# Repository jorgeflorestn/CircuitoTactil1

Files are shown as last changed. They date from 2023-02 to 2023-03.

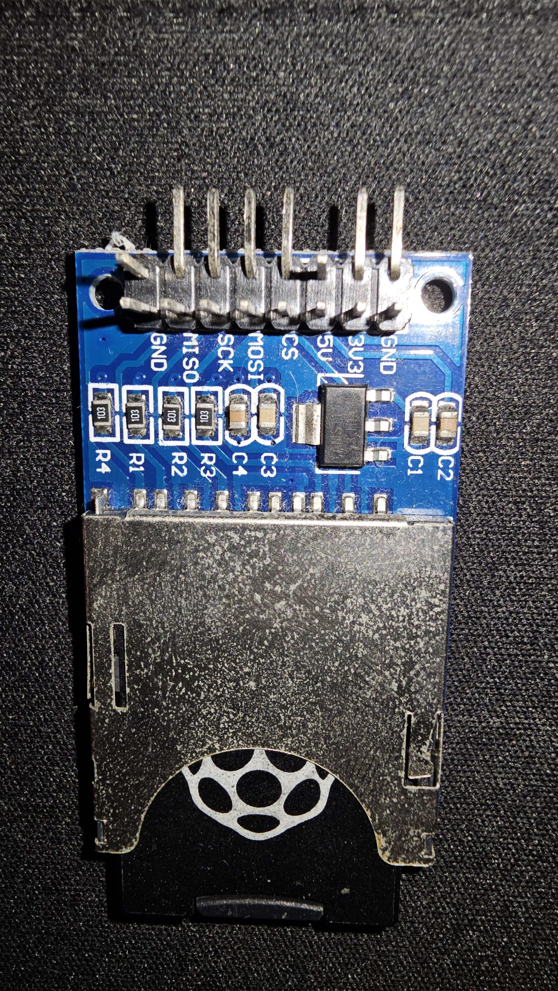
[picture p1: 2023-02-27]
Pictures/Diagrams/20230223_190610.jpg

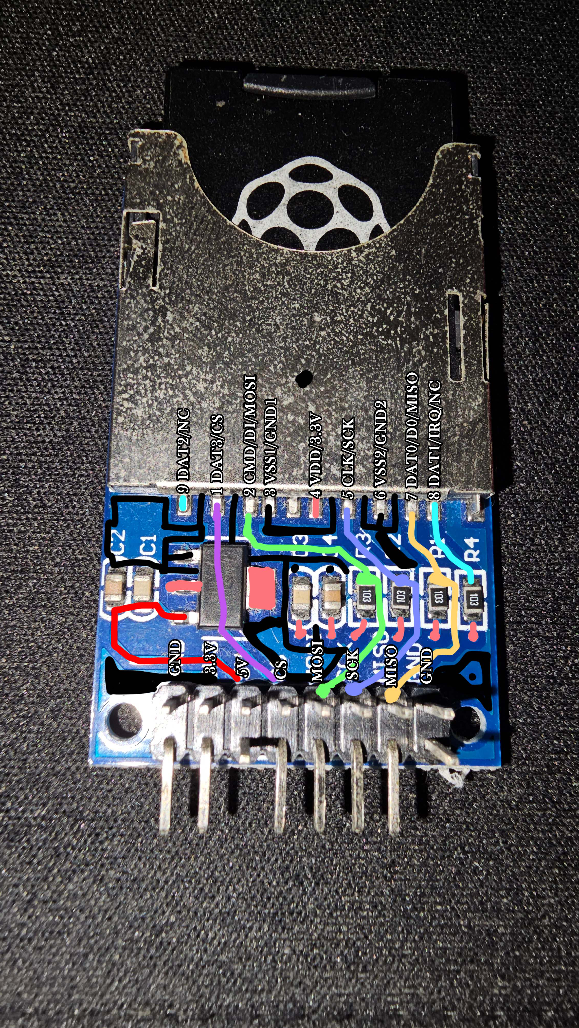
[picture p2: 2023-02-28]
Pictures/Diagrams/20230223_190610S.jpg

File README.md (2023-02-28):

# Circuito Tactil NTC UADY-CICY
Circuito para la detección de contacto en sensores nanoestructurados.

## Por hacer y revisar (de prioritario a no urgente)
- **Checar valores de _resistencias y capacitores_.**
<sub>(los del regulador deben ser 10uF en ambas salidas para evitar ruido, poner en paralelo uno de 100nf ceramico para reducir la Rint de ambos)</sub>
- Hacer tabla con características de mcu/mux/potdig/opamp para presentar a Francis y compararlo con equipo Keysight 34980A y 32923A
- ~~Añadir capacitores al lado de la entrada de 3.3v MCU ✓~~
- ~~Controlar la salida 2 del regulador para encender/apagar circuitos ✓~~ (checar consumo? aguanta el ic?)
- ~~Conectar MCU a pines ✓~~
- ~~Revisar mosfet Q1, se están usando como canal P y no N ✓~~
- ~~Validar secuencia en MUXes ✓~~(Checar que cable plano tenga los mismos pines en ambos extremos 1:1)
- ~~Editar footprint de nina para quitar todos los gpio no usados ✓~~
- ~~Validar conexión spi y componentes para micro SD ✓~~
- ~~Etiquetas en pines. ✓~~
- ~~tapar vias no importantes (reduciendo su tamaño <13 mils) ✓~~

## Extras a añadir
- ~~Añadir headers para sacar I2C y SPI ✓~~
- ~~Añadir testpoints en muxes ✓~~
- ~~Jumper para saltar de 3.3v a 5v ✓~~

### Si nos da tiempo 
- Añadir ic para carga y descarga de baterías (queda un espacio grande donde podemos añadir el cargador de pilas)
**(Si se añade, se debe aislar los 5v del usb y los 4.2 de la pila)**.
- Integrar ADC ADS1220 (FUTURO (puerto i2c disponible))
- ~~Añadir conector plano de +42 pines (básicamente se añadió en el punto de los testpoints en muxes)~~

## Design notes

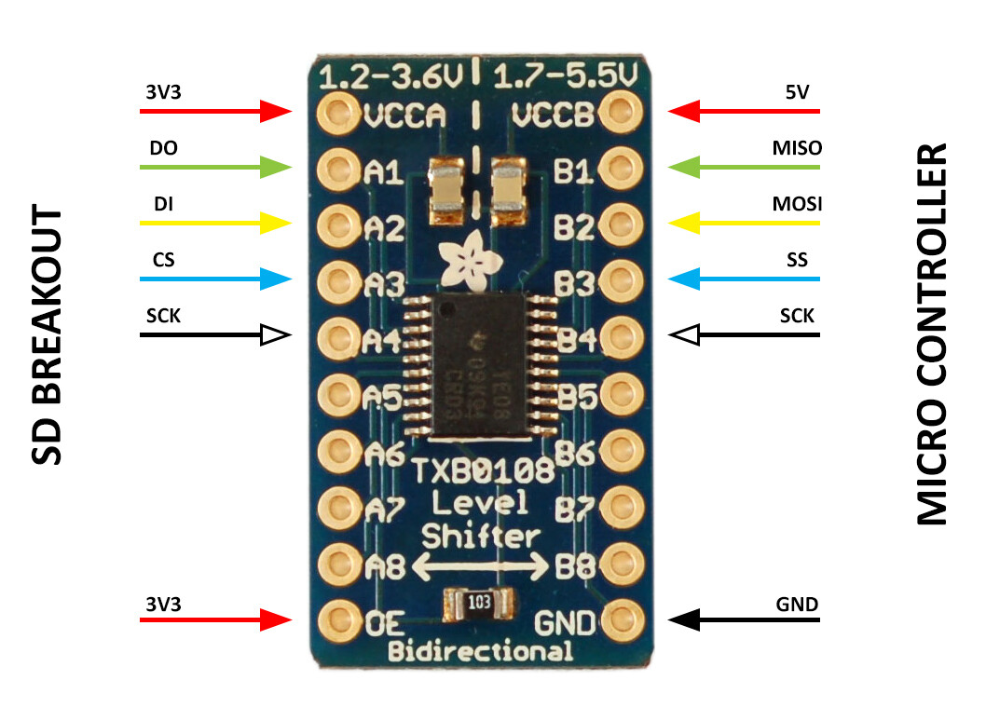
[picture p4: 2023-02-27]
Pictures/Diagrams/txb0108_LRG-amk.jpg

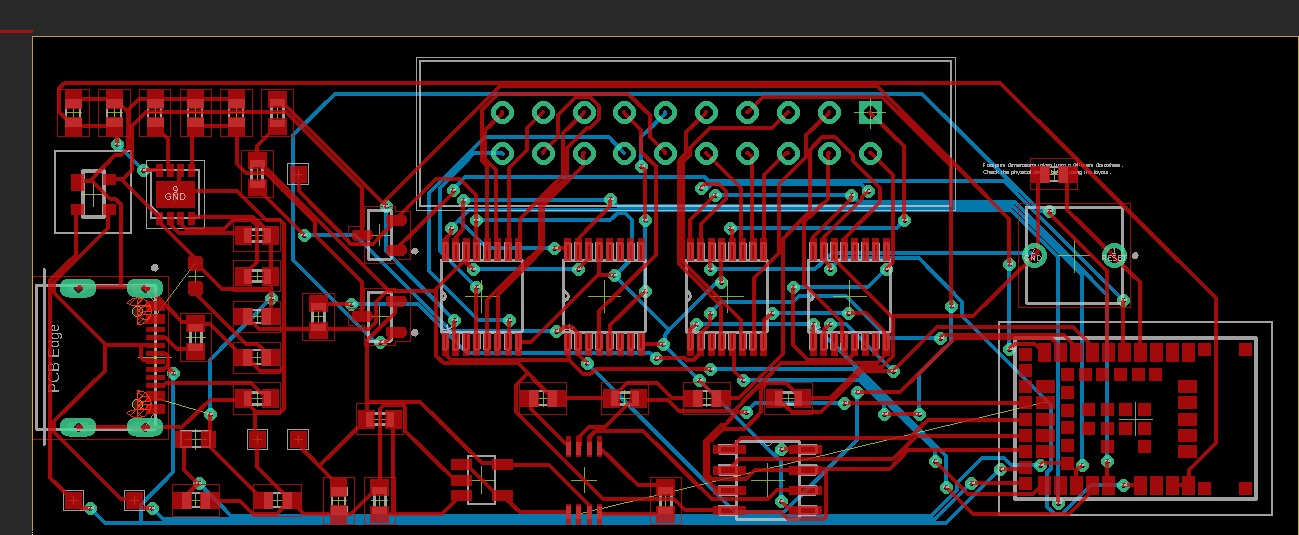
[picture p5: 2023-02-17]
Pictures/Diagrams/WhatsApp Image 2023-02-15 at 4.39.45 PM.jpeg

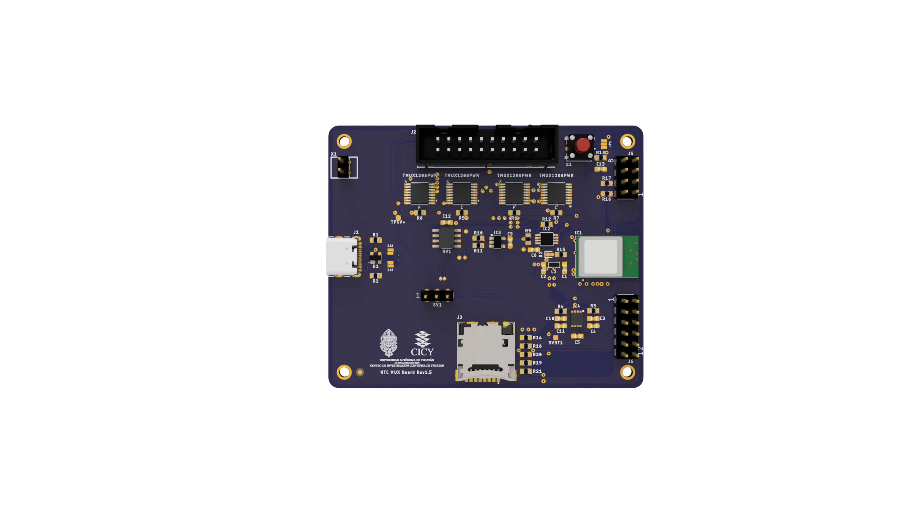
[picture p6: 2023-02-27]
Pictures/7006e35c-3277-4497-81c9-2658856942b5.PNG

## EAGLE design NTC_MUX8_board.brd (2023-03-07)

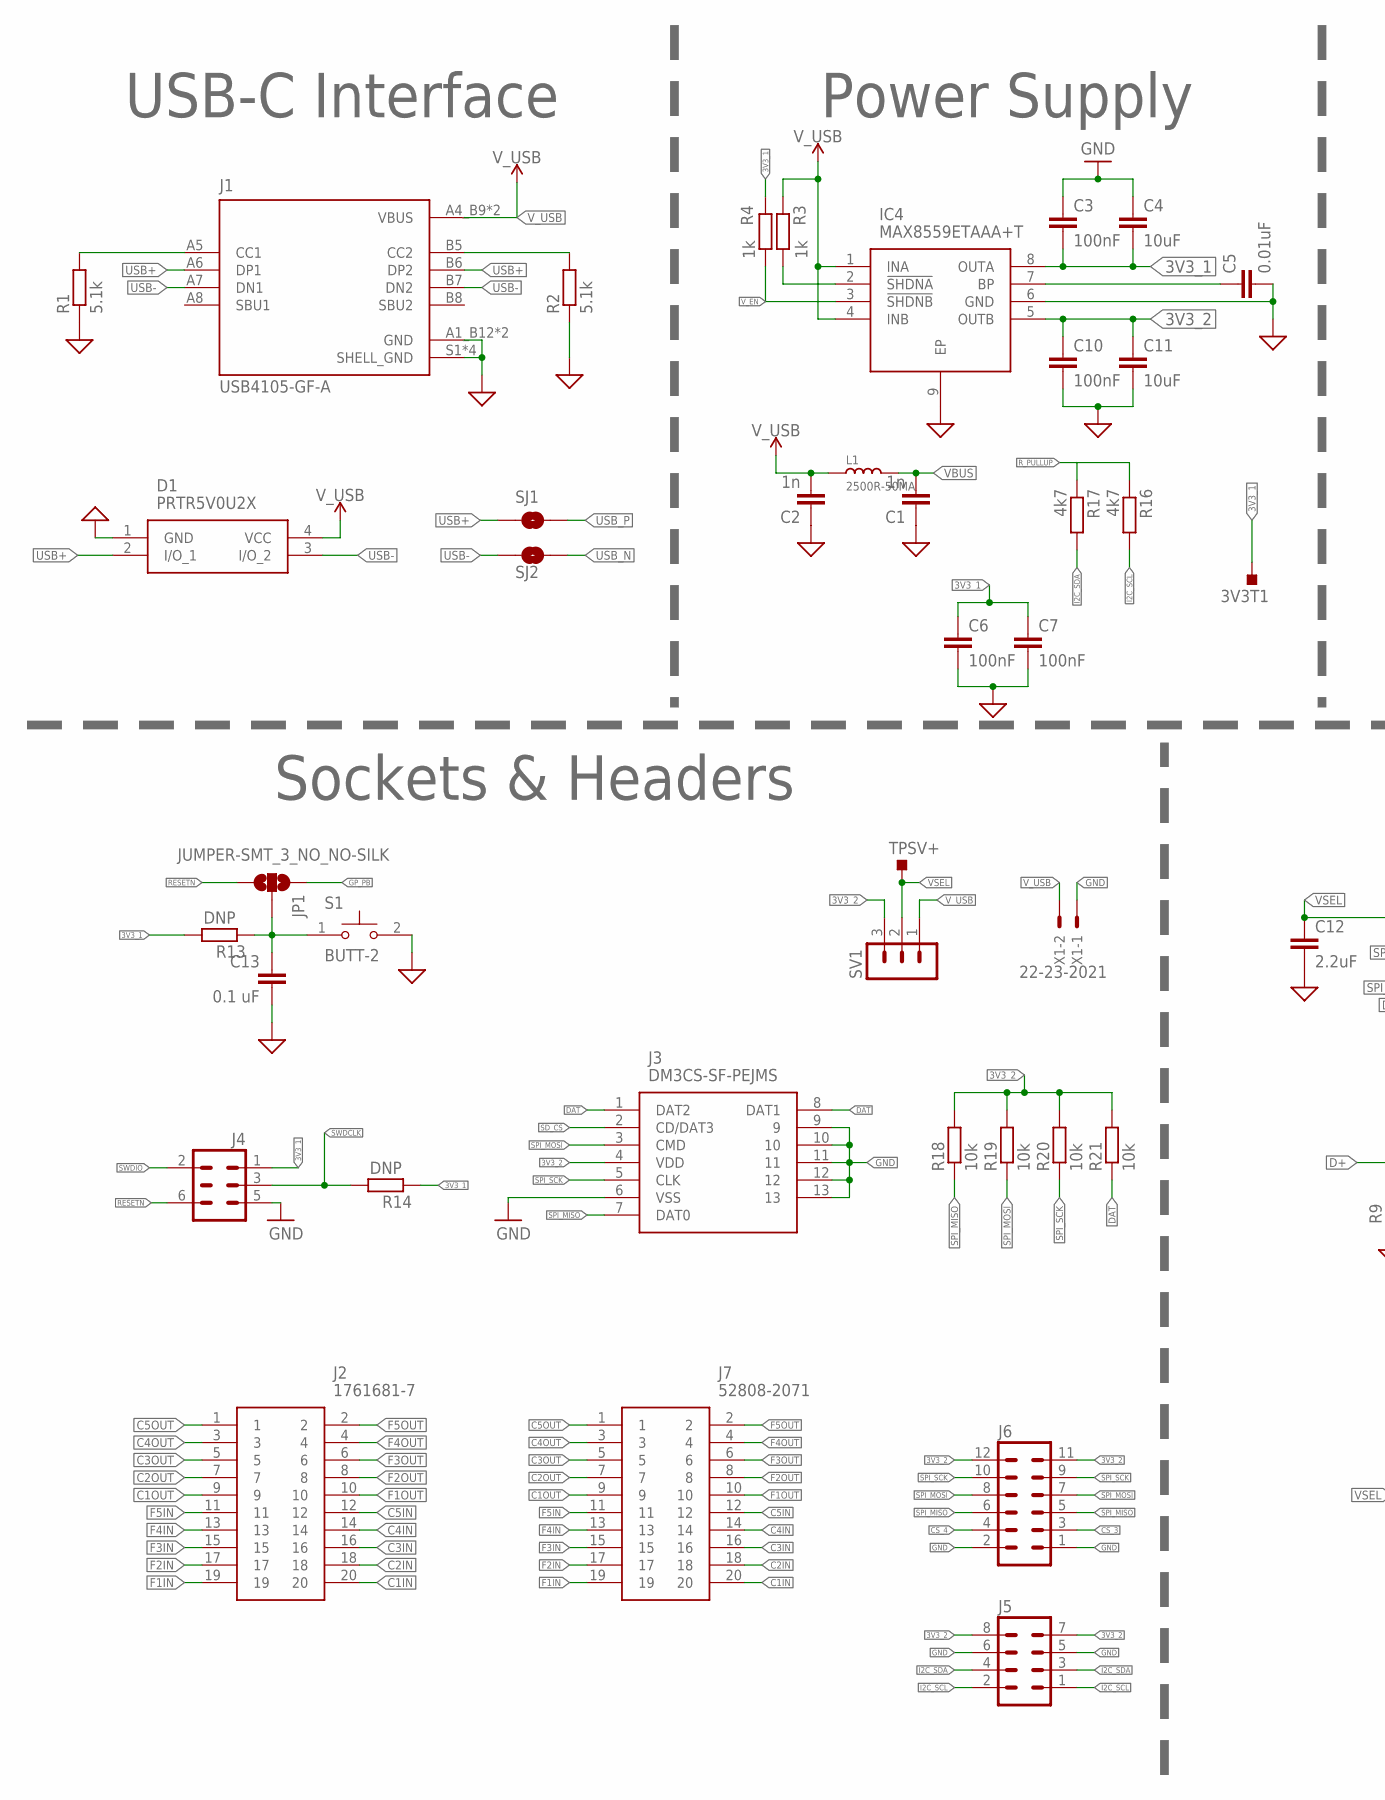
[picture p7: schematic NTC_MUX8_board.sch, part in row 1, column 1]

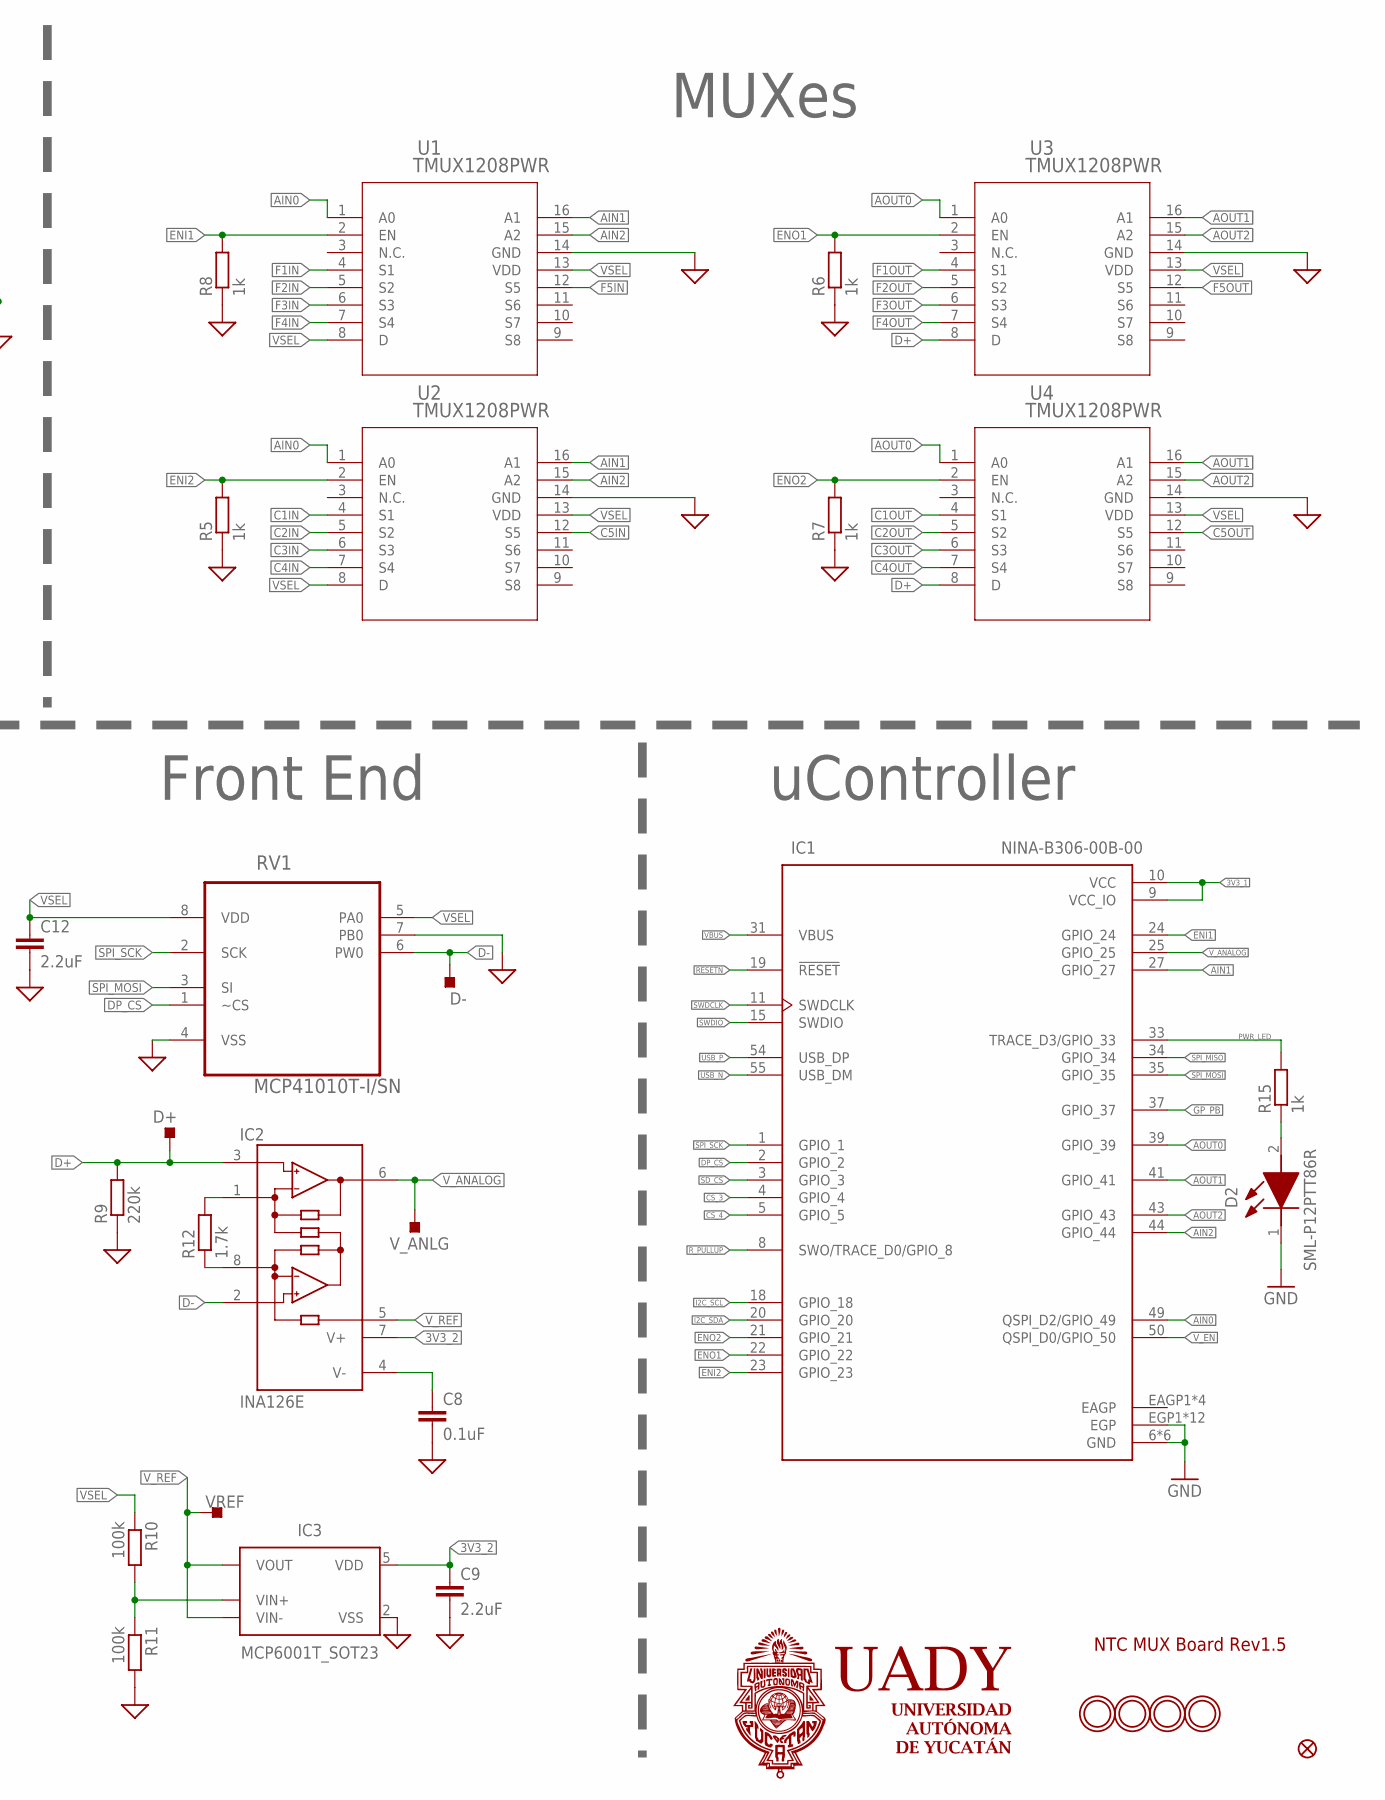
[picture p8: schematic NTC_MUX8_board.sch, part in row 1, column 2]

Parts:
3V3T1: TESTPOINT_TPS-SMD-10SN; TESTPOINT_SMD-10SN
C1, C2: 1n; C0603
C3, C6, C7, C10: 100nF; C0603
C4, C11: 10uF; C0603
C5: 0.01uF; C0603
C8: 0.1uF; C0603
C9, C12: 2.2uF; C0603
C13: 0.1 uF; C0603
D1: PRTR5V0U2X
D2: SML-P12PTT86R; LEDC1006X25N
D+: TESTPOINT_TPS-SMD-10SN; TESTPOINT_SMD-10SN
D-: TESTPOINT_TPS-SMD-10SN; TESTPOINT_SMD-10SN
FID1: FIDUCIAL_1MM
IC1: NINA-B306-00B-00; XCVR_NINA-B306-00B-00
IC2: INA126E; MSOP08
IC3: MCP6001T_SOT23; SOT95P280X145-5N
IC4: MAX8559ETAAA+T; SON65P300X300X80-9N
J1: USB4105-GF-A; GCT_USB4105-GF-A
J2: 1761681-7; SHDR20W66P254_2X10_3302X883X92
J3: DM3CS-SF-PEJMS; DM3CSSFPEJMS
J4: DNP; 2X03-TP1
J5: MA04-2
J6: MA06-2
J7: 52808-2071; 528082071
JP1: JUMPER-SMT_3_NO_NO-SILK; SMT-JUMPER_3_NO_NO-SILK
L1: 2500R-50MA; L0603
R1, R2: 5.1k; R0603
R3, R4, R5, R6, R7, R8, R15: 1k; R0603
R9: 220k; R0603
R10, R11: 100k; R0603
R12: 1.7k; R0603
R13, R14: DNP; R0603
R16, R17: 4k7; R0603
R18, R19, R20, R21: 10k; R0603
RV1: MCP41010T-I/SN; SOIC127P600X175-8N
S1: BUTT-2; SW_BUTT-2
SJ1, SJ2: JUMPER-SMT_2_NO_NO-SILK; SMT-JUMPER_2_NO_NO-SILK
SV1: MA03-1
TPSV+: TESTPOINT_TPS-SMD-10SN; TESTPOINT_SMD-10SN
U1, U2, U3, U4: TMUX1208PWR; PW_16_TEX
U$2, U$3, U$4, U$24: MOUNTINGHOLE2.5; MOUNTINGHOLE_2.5_PLATED
VREF: TESTPOINT_TPS-SMD-10SN; TESTPOINT_SMD-10SN
V_ANLG: TESTPOINT_TPS-SMD-10SN; TESTPOINT_SMD-10SN
X1: 22-23-2021

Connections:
3V3_1: 3V3T1.TP, C3.2, C4.2, C6.1, C7.1, IC1.9 (VCC_IO), IC1.10 (VCC), IC4.8 (OUTA), J4.1, R4.1, R13.2, R14.1
3V3_2: C9.1, C10.1, C11.1, IC2.7 (V+), IC3.5 (VDD), IC4.5 (OUTB), J3.4 (VDD), J5.7, J5.8, J6.11, J6.12, R18.2, R19.2, R20.2, R21.2, SV1.3
AIN0: IC1.49 (QSPI_D2/GPIO_49), U1.1 (A0), U2.1 (A0)
AIN1: IC1.27 (GPIO_27), U1.16 (A1), U2.16 (A1)
AIN2: IC1.44 (GPIO_44), U1.15 (A2), U2.15 (A2)
AOUT0: IC1.39 (GPIO_39), U3.1 (A0), U4.1 (A0)
AOUT1: IC1.41 (GPIO_41), U3.16 (A1), U4.16 (A1)
AOUT2: IC1.43 (GPIO_43), U3.15 (A2), U4.15 (A2)
C1IN: J2.20, J7.20, U2.4 (S1)
C1OUT: J2.9, J7.9, U4.4 (S1)
C2IN: J2.18, J7.18, U2.5 (S2)
C2OUT: J2.7, J7.7, U4.5 (S2)
C3IN: J2.16, J7.16, U2.6 (S3)
C3OUT: J2.5, J7.5, U4.6 (S3)
C4IN: J2.14, J7.14, U2.7 (S4)
C4OUT: J2.3, J7.3, U4.7 (S4)
C5IN: J2.12, J7.12, U2.12 (S5)
C5OUT: J2.1, J7.1, U4.12 (S5)
CS_3: IC1.4 (GPIO_4), J6.3
CS_4: IC1.5 (GPIO_5), J6.4
D+: D+.TP, IC2.3 (+IN), R9.2, U3.8 (D), U4.8 (D)
D-: D-.TP, IC2.2 (-IN), RV1.6 (PW0)
DAT: J3.1 (DAT2), J3.8 (DAT1), R21.1
DP_CS: IC1.2 (GPIO_2), RV1.1 (~CS)
EAGP: IC1.EAGP1 (EAGP), IC1.EAGP2 (EAGP), IC1.EAGP3 (EAGP), IC1.EAGP4 (EAGP)
ENI1: IC1.24 (GPIO_24), R8.2, U1.2 (EN)
ENI2: IC1.23 (GPIO_23), R5.2, U2.2 (EN)
ENO1: IC1.22 (GPIO_22), R6.2, U3.2 (EN)
ENO2: IC1.21 (GPIO_21), R7.2, U4.2 (EN)
F1IN: J2.19, J7.19, U1.4 (S1)
F1OUT: J2.10, J7.10, U3.4 (S1)
F2IN: J2.17, J7.17, U1.5 (S2)
F2OUT: J2.8, J7.8, U3.5 (S2)
F3IN: J2.15, J7.15, U1.6 (S3)
F3OUT: J2.6, J7.6, U3.6 (S3)
F4IN: J2.13, J7.13, U1.7 (S4)
F4OUT: J2.4, J7.4, U3.7 (S4)
F5IN: J2.11, J7.11, U1.12 (S5)
F5OUT: J2.2, J7.2, U3.12 (S5)
GND: C1.1, C2.1, C3.1, C4.1, C5.2, C6.2, C7.2, C8.2, C9.2, C10.2, C11.2, C12.2, C13.2, D1.1 (GND), D2.1 (K), IC1.6 (GND), IC1.12 (GND), IC1.14 (GND), IC1.26 (GND), IC1.30 (GND), IC1.53 (GND), IC1.EGP1 (EGP), IC1.EGP2 (EGP), IC1.EGP3 (EGP), IC1.EGP4 (EGP), IC1.EGP5 (EGP), IC1.EGP6 (EGP), IC1.EGP7 (EGP), IC1.EGP8 (EGP), IC1.EGP9 (EGP), IC1.EGP10 (EGP), IC1.EGP11 (EGP), IC1.EGP12 (EGP), IC3.2 (VSS), IC4.6 (GND), IC4.9 (EP), J1.A1_B12 (GND), J1.B1_A12 (GND), J1.S1 (SHELL_GND), J1.S2 (SHELL_GND), J1.S3 (SHELL_GND), J1.S4 (SHELL_GND), J3.6 (VSS), J3.9, J3.10, J3.11, J3.12, J3.13, J4.5, J5.5, J5.6, J6.1, J6.2, R1.1, R2.1, R5.1, R6.1, R7.1, R8.1, R9.1, R11.2, RV1.4 (VSS), RV1.7 (PB0), S1.2, U1.14 (GND), U2.14 (GND), U3.14 (GND), U4.14 (GND), X1.1
GP_PB: IC1.37 (GPIO_37), JP1.3
I2C_SCL: IC1.18 (GPIO_18), J5.1, J5.2, R16.2
I2C_SDA: IC1.20 (GPIO_20), J5.3, J5.4, R17.2
unnamed: J1.A5 (CC1), R1.2
unnamed: IC4.2 (!SHDNA), R3.2
unnamed: D2.2 (A), R15.1
unnamed: IC2.1 (RG), R12.2
unnamed: C5.1, IC4.7 (BP)
unnamed: IC2.8 (RG), R12.1
unnamed: C8.1, IC2.4 (V-)
unnamed: J1.B5 (CC2), R2.2
unnamed: IC3.3 (VIN+), R10.2, R11.1
PWR_LED: IC1.33 (TRACE_D3/GPIO_33), R15.2
RESET: C13.1, JP1.2, R13.1, S1.1
RESETN: IC1.19 (!RESET), J4.6, JP1.1
R_PULLUP: IC1.8 (SWO/TRACE_D0/GPIO_8), R16.1, R17.1
SD_CS: IC1.3 (GPIO_3), J3.2 (CD/DAT3)
SPI_MISO: IC1.34 (GPIO_34), J3.7 (DAT0), J6.5, J6.6, R18.1
SPI_MOSI: IC1.35 (GPIO_35), J3.3 (CMD), J6.7, J6.8, R19.1, RV1.3 (SI)
SPI_SCK: IC1.1 (GPIO_1), J3.5 (CLK), J6.9, J6.10, R20.1, RV1.2 (SCK)
SWDCLK: IC1.11 (SWDCLK), J4.3, R14.2
SWDIO: IC1.15 (SWDIO), J4.2
USB+: D1.2 (I/O_1), J1.A6 (DP1), J1.B6 (DP2), SJ1.1
USB-: D1.3 (I/O_2), J1.A7 (DN1), J1.B7 (DN2), SJ2.1
USB_N: IC1.55 (USB_DM), SJ2.2
USB_P: IC1.54 (USB_DP), SJ1.2
VBUS: C1.2, IC1.31 (VBUS), L1.2
VSEL: C12.1, R10.1, RV1.5 (PA0), RV1.8 (VDD), SV1.2, TPSV+.TP, U1.8 (D), U1.13 (VDD), U2.8 (D), U2.13 (VDD), U3.13 (VDD), U4.13 (VDD)
V_ANALOG: IC1.25 (GPIO_25), IC2.6 (OUT), V_ANLG.TP
V_EN: IC1.50 (QSPI_D0/GPIO_50), IC4.3 (!SHDNB), R4.2
V_REF: IC2.5 (REF), IC3.1 (VOUT), IC3.4 (VIN-), VREF.TP
V_USB: C2.2, D1.4 (VCC), IC4.1 (INA), IC4.4 (INB), J1.A4_B9 (VBUS), J1.B4_A9 (VBUS), L1.1, R3.1, SV1.1, X1.2

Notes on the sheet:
uController
Sockets & Headers
MUXes
Power Supply
USB-C Interface
Front End
NTC MUX Board Rev1.5

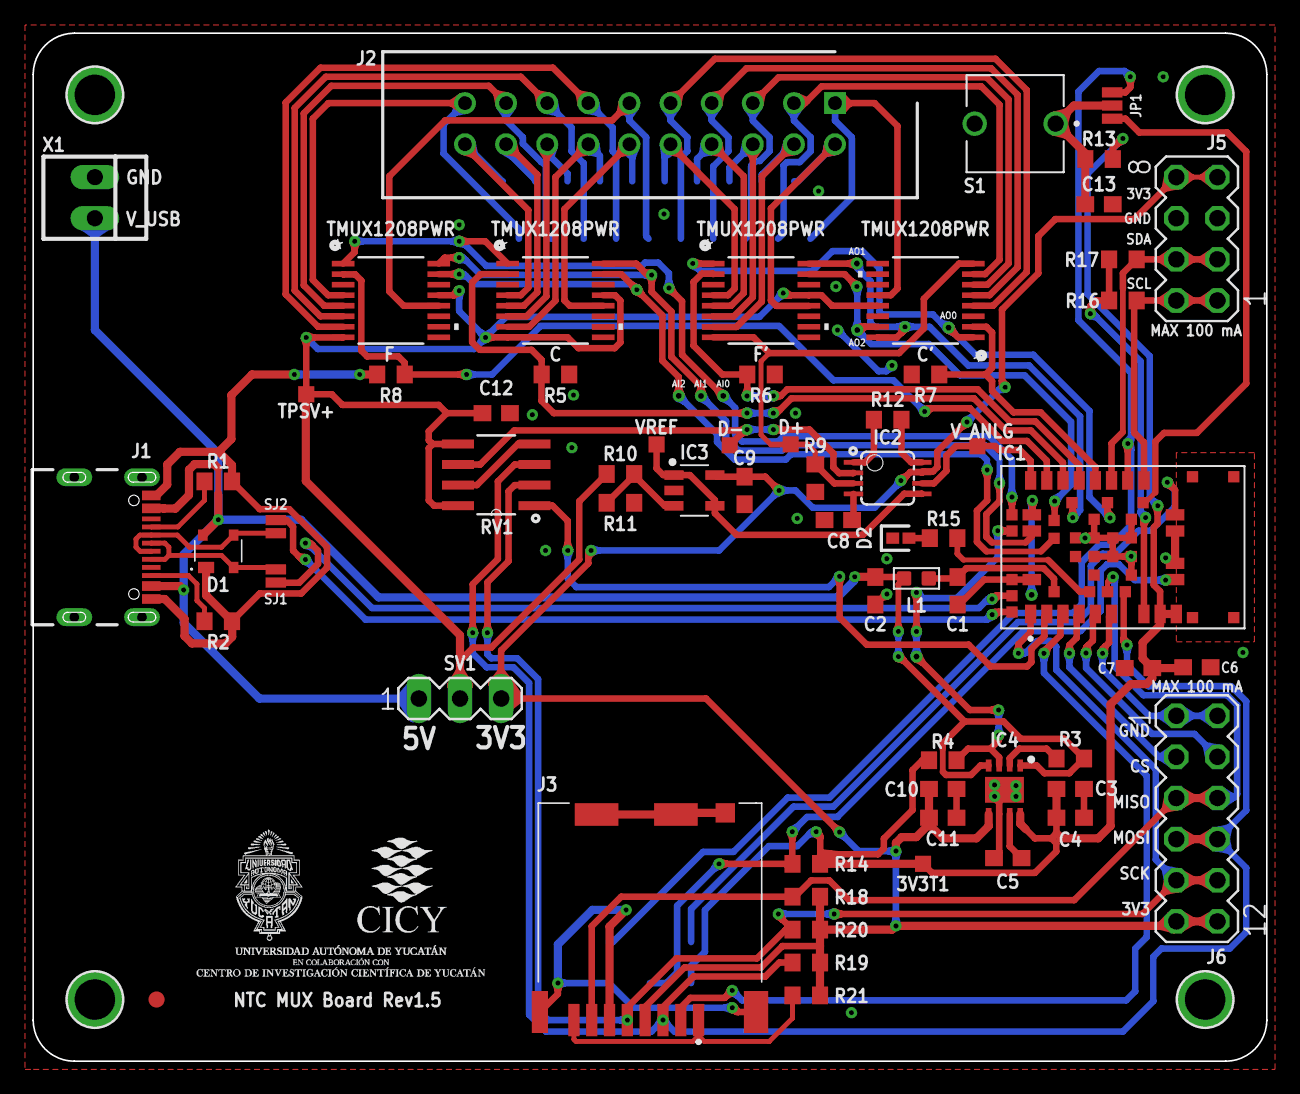
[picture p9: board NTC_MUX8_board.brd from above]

Board: 2 copper layers, 76.2 x 63.5 mm, 71 parts (1 on the bottom side), 72 nets.

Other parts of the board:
U$5: UADY-CICY-MID

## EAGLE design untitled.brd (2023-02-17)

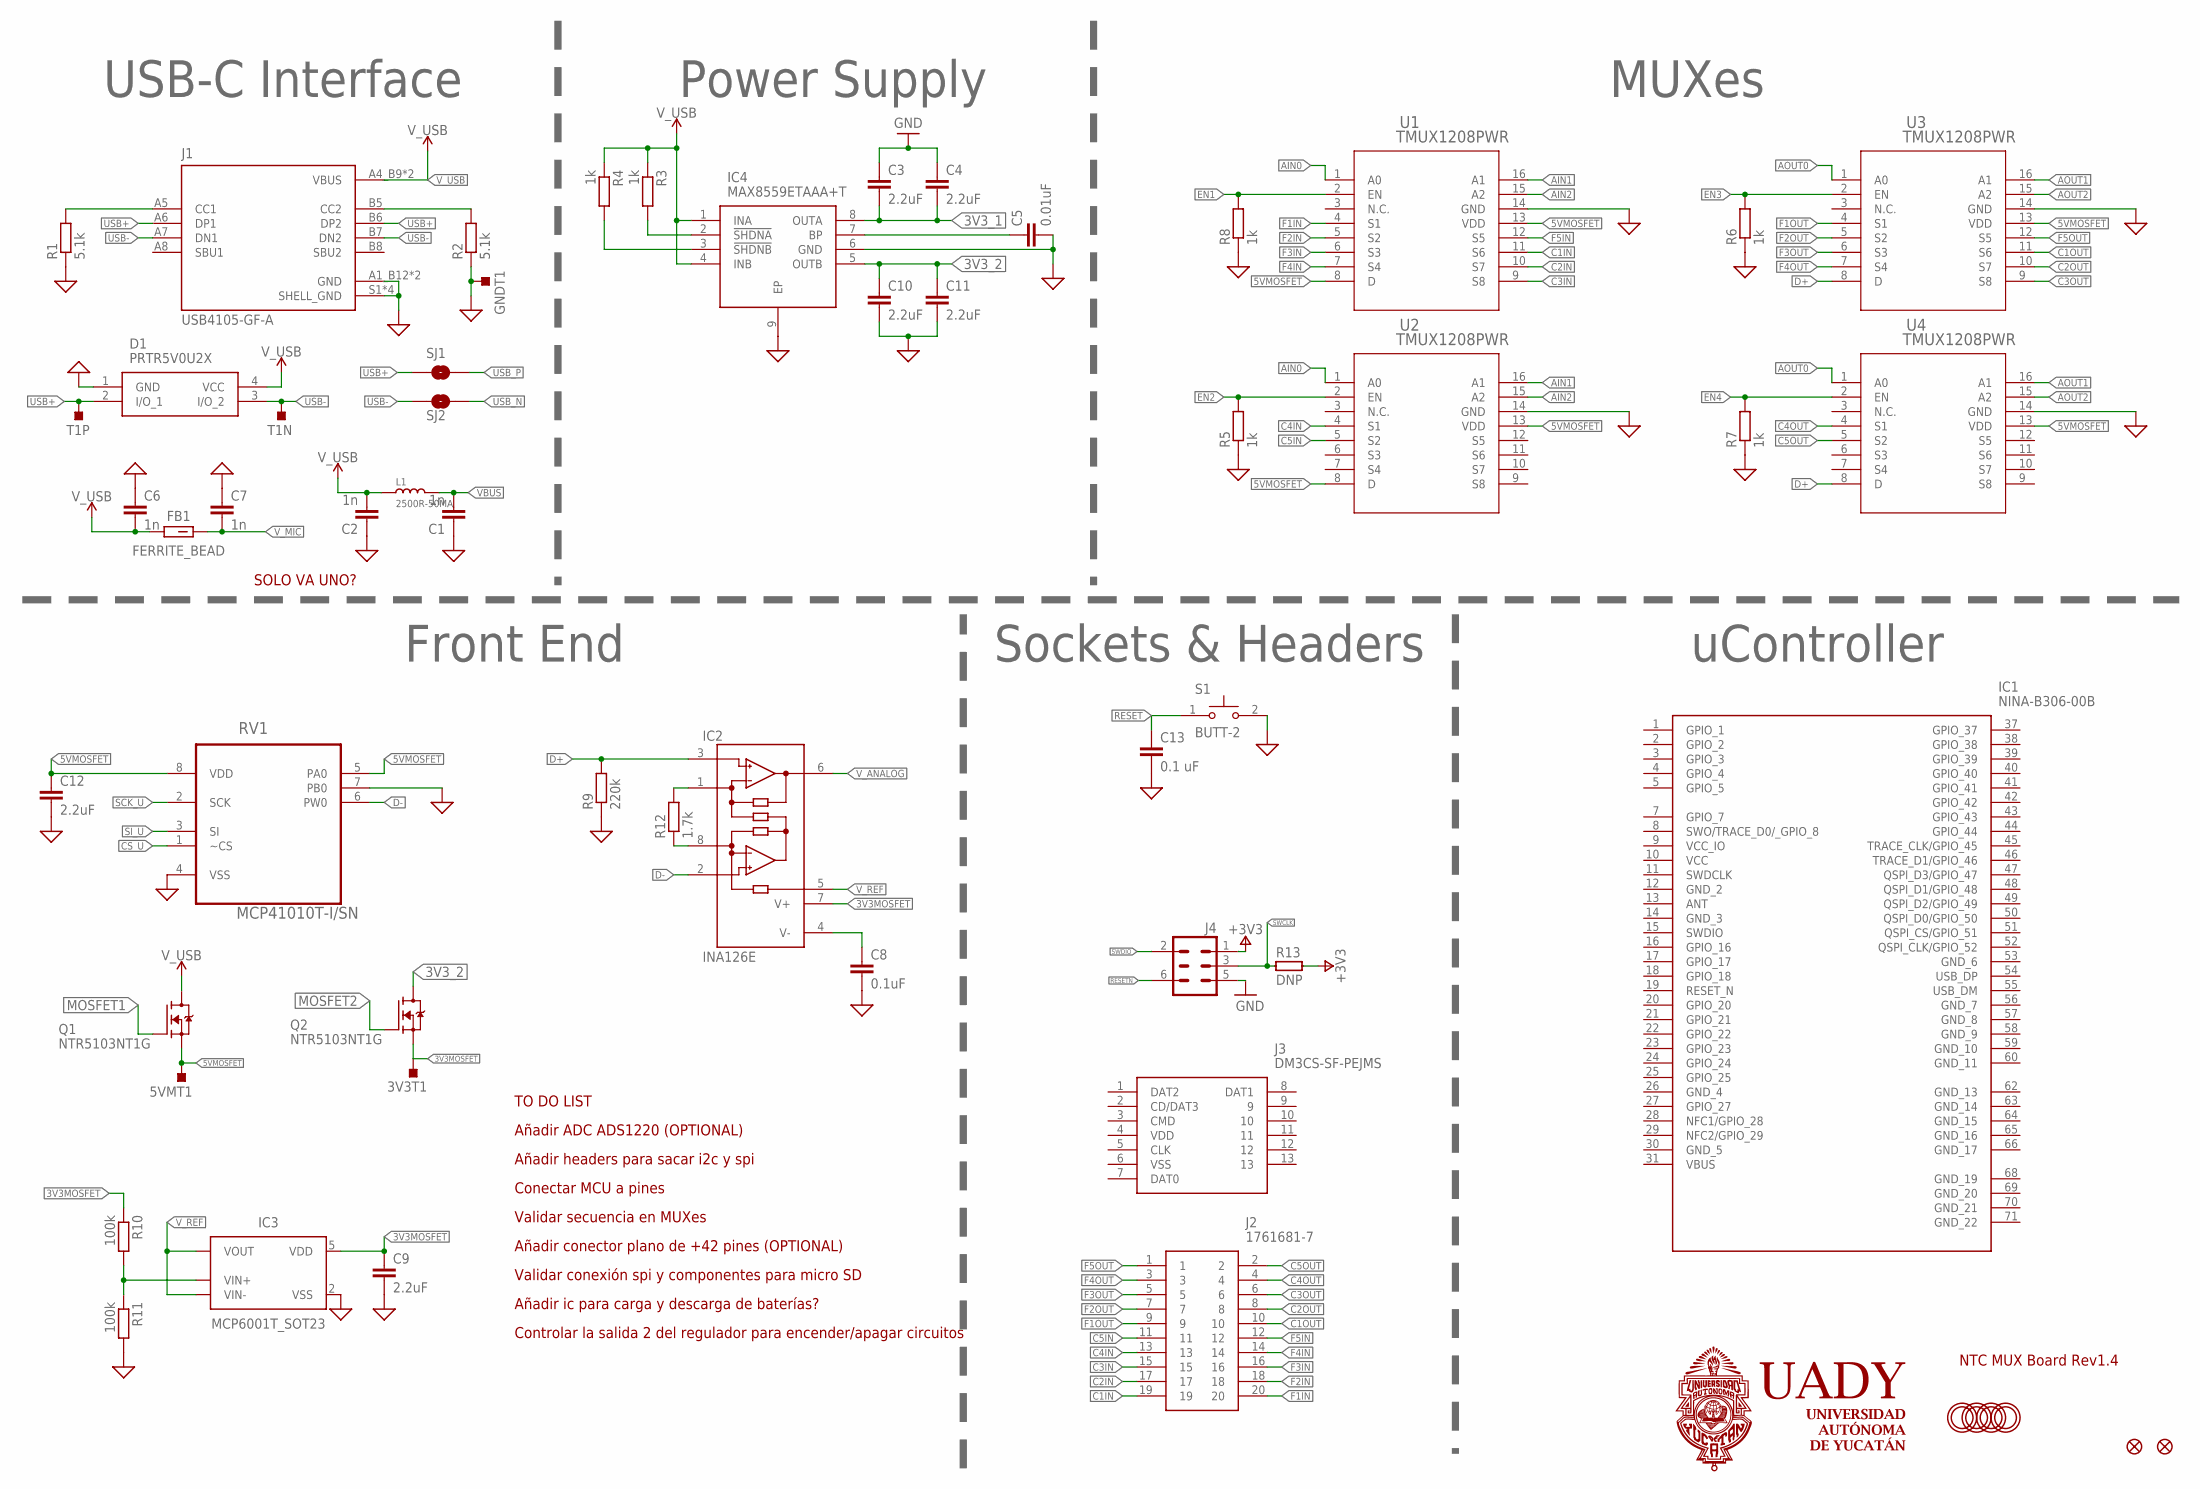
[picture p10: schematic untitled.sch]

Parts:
3V3T1, 5VMT1: TESTPOINT_TPS-SMD-10SN; TESTPOINT_SMD-10SN
C1, C2, C6, C7: 1n; C0603
C3, C4, C9, C10, C11, C12: 2.2uF; C0603
C5: 0.01uF; C0603
C8: 0.1uF; C0603
C13: 0.1 uF; C0603
D1: PRTR5V0U2X
FB1: FERRITE_BEAD; BEADC1608X95N
FID1, FID4: FIDUCIAL_1MM
GNDT1: TESTPOINT_TPS-SMD-10SN; TESTPOINT_SMD-10SN
IC1: NINA-B306-00B; NINAB30600B
IC2: INA126E; MSOP08
IC3: MCP6001T_SOT23; SOT95P280X145-5N
IC4: MAX8559ETAAA+T; SON65P300X300X80-9N
J1: USB4105-GF-A; GCT_USB4105-GF-A
J2: 1761681-7; SHDR20W66P254_2X10_3302X883X92
J3: DM3CS-SF-PEJMS; DM3CSSFPEJMS
J4: DNP; 2X03-TP1
L1: 2500R-50MA; L0603
Q1, Q2: NTR5103NT1G; SOT95P237X111-3N
R1, R2: 5.1k; R0603
R3, R4, R5, R6, R7, R8: 1k; R0603
R9: 220k; R0603
R10, R11: 100k; R0603
R12: 1.7k; R0603
R13: DNP; 0402-1005X55N
RV1: MCP41010T-I/SN; SOIC127P600X175-8N
S1: BUTT-2; SW_BUTT-2
SJ1, SJ2: JUMPER-SMT_2_NO_NO-SILK; SMT-JUMPER_2_NO_NO-SILK
T1N, T1P: TESTPOINT_TPS-SMD-10SN; TESTPOINT_SMD-10SN
U1, U2, U3, U4: TMUX1208PWR; PW_16_TEX
U$2, U$3, U$4, U$24: MOUNTINGHOLE2.5; MOUNTINGHOLE_2.5_PLATED

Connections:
3V3MOSFET: 3V3T1.TP, C9.1, IC2.7 (V+), IC3.5 (VDD), Q2.2 (S), R10.1
3V3_1: C3.2, C4.2, IC4.8 (OUTA)
3V3_2: C10.1, C11.1, IC4.5 (OUTB), Q2.3 (D)
5VMOSFET: 5VMT1.TP, C12.1, Q1.2 (S), RV1.5 (PA0), RV1.8 (VDD), U1.8 (D), U1.13 (VDD), U2.8 (D), U2.13 (VDD), U3.13 (VDD), U4.13 (VDD)
+3V3: J4.1, R13.1
AIN0: U1.1 (A0), U2.1 (A0)
AIN1: U1.16 (A1), U2.16 (A1)
AIN2: U1.15 (A2), U2.15 (A2)
AOUT0: U3.1 (A0), U4.1 (A0)
AOUT1: U3.16 (A1), U4.16 (A1)
AOUT2: U3.15 (A2), U4.15 (A2)
C1IN: J2.19, U1.11 (S6)
C1OUT: J2.10, U3.11 (S6)
C2IN: J2.17, U1.10 (S7)
C2OUT: J2.8, U3.10 (S7)
C3IN: J2.15, U1.9 (S8)
C3OUT: J2.6, U3.9 (S8)
C4IN: J2.13, U2.4 (S1)
C4OUT: J2.4, U4.4 (S1)
C5IN: J2.11, U2.5 (S2)
C5OUT: J2.2, U4.5 (S2)
CS_U: RV1.1 (~CS)
D+: IC2.3 (+IN), R9.2, U3.8 (D), U4.8 (D)
D-: IC2.2 (-IN), RV1.6 (PW0)
EN1: R8.2, U1.2 (EN)
EN2: R5.2, U2.2 (EN)
EN3: R6.2, U3.2 (EN)
EN4: R7.2, U4.2 (EN)
F1IN: J2.20, U1.4 (S1)
F1OUT: J2.9, U3.4 (S1)
F2IN: J2.18, U1.5 (S2)
F2OUT: J2.7, U3.5 (S2)
F3IN: J2.16, U1.6 (S3)
F3OUT: J2.5, U3.6 (S3)
F4IN: J2.14, U1.7 (S4)
F4OUT: J2.3, U3.7 (S4)
F5IN: J2.12, U1.12 (S5)
F5OUT: J2.1, U3.12 (S5)
GND: C1.1, C2.1, C3.1, C4.1, C5.2, C6.1, C7.1, C8.2, C9.2, C10.2, C11.2, C12.2, C13.2, D1.1 (GND), GNDT1.TP, IC3.2 (VSS), IC4.6 (GND), IC4.9 (EP), J1.A1_B12 (GND), J1.B1_A12 (GND), J1.S1 (SHELL_GND), J1.S2 (SHELL_GND), J1.S3 (SHELL_GND), J1.S4 (SHELL_GND), J4.5, R1.1, R2.1, R5.1, R6.1, R7.1, R8.1, R9.1, R11.2, RV1.4 (VSS), RV1.7 (PB0), S1.2, U1.14 (GND), U2.14 (GND), U3.14 (GND), U4.14 (GND)
MOSFET1: Q1.1 (G)
MOSFET2: Q2.1 (G)
unnamed: J1.A5 (CC1), R1.2
unnamed: IC4.2 (!SHDNA), R3.2
unnamed: IC4.3 (!SHDNB), R4.2
unnamed: IC2.1 (RG), R12.2
unnamed: C5.1, IC4.7 (BP)
unnamed: IC2.8 (RG), R12.1
unnamed: C8.1, IC2.4 (V-)
unnamed: J1.B5 (CC2), R2.2
unnamed: IC3.3 (VIN+), R10.2, R11.1
RESET: C13.1, S1.1
RESETN: J4.6
SCK_U: RV1.2 (SCK)
SI_U: RV1.3 (SI)
SWCLK: J4.3, R13.2
SWDIO: J4.2
USB+: D1.2 (I/O_1), J1.A6 (DP1), J1.B6 (DP2), SJ1.1, T1P.TP
USB-: D1.3 (I/O_2), J1.A7 (DN1), J1.B7 (DN2), SJ2.1, T1N.TP
USB_N: SJ2.2
USB_P: SJ1.2
VBUS: C1.2, L1.2
V_ANALOG: IC2.6 (OUT)
V_MIC: C7.2, FB1.2
V_REF: IC2.5 (REF), IC3.1 (VOUT), IC3.4 (VIN-)
V_USB: C2.2, C6.2, D1.4 (VCC), FB1.1, IC4.1 (INA), IC4.4 (INB), J1.A4_B9 (VBUS), J1.B4_A9 (VBUS), L1.1, Q1.3 (D), R3.1, R4.1

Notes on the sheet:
uController
Sockets & Headers
MUXes
Power Supply
USB-C Interface
Front End
NTC MUX Board Rev1.4
Añadir ADC ADS1220 (OPTIONAL)
Añadir headers para sacar i2c y spi
Conectar MCU a pines
Validar secuencia en MUXes
Añadir conector plano de +42 pines (OPTIONAL)
TO DO LIST
SOLO VA UNO?
Validar conexión spi y componentes para micro SD
Añadir ic para carga y descarga de baterías?
Controlar la salida 2 del regulador para encender/apagar circuitos

Board: 2 copper layers, 59 parts (0 on the bottom side), 55 nets, no tracks yet.

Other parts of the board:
U$5: UADY-CICY-MID

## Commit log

2023-02-10 Add files via upload
    1
    [untitled.brd, untitled.sch]
2023-02-14 Reset arrange insert
    [untitled.brd, untitled.sch]
2023-02-17 first edit
    [untitled.brd, untitled.sch]
2023-02-17 lista actualizada de pendientes
    faltan algunas cosas, pero la base ya está para solo unir y rutear
    [untitled.brd, untitled.sch]
2023-02-17 3d models updated
    [NTC_MUX8_board.brd, NTC_MUX8_board.sch]
2023-02-24 detalles
    faltan los detalles marcados en el esquemático
    [NTC_MUX8_board.brd, NTC_MUX8_board.sch]
2023-02-27 Pequeños errores y adición de mejoras
    [NTC_MUX8_board.brd, NTC_MUX8_board.sch]
2023-02-28 casi listo
    añadidas etiquetas y mejora del ruteo de algunas pistas
    [NTC_MUX8_board.brd]
2023-02-28 beta finalizada
    circuito listo a mi parecer
    [NTC_MUX8_board.brd, NTC_MUX8_board.sch]
2023-02-28 primer gerber
    gerber y cotización
2023-02-28 minor corrections
    corrección v en seguidor
    y pistas
    [NTC_MUX8_board.brd, NTC_MUX8_board.sch]
2023-03-01 test points on front end
    [NTC_MUX8_board.brd, NTC_MUX8_board.sch]
2023-03-07 teardrops en vias y pines
    [NTC_MUX8_board.brd]

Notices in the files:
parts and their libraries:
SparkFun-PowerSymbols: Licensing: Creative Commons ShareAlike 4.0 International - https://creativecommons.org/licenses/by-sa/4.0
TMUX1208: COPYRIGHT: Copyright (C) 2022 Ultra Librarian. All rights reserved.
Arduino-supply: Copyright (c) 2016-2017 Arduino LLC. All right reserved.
